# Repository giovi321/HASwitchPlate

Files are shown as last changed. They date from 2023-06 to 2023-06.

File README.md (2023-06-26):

# This is an alternative repository for monunting the display horizontally

The HASwitchPlate project has evolved since. The original creator made a new awesome version, hovewer it is too much work to make the new version compatible with horizontal mounts of the display (i.e., to fit in a 503 electrical box).
Please note that all the pictures in this repository have not been updated to match the horizontal design of the display.
The substantial changes to the design and configuration of the display to make it horizontal are in the folders:
  - 3D_Printable_Models/Horizontal version
  - Nextion_HMI/Horizontal version

The new version of the device and related software and firmware is called [HASPone](https://github.com/HASwitchPlate/HASPone).

---

# HA SwitchPlate

The HA SwitchPlate is a user-programmable LCD touchscreen you can mount into a [standard North American work box](https://www.nema.org/Standards/ComplimentaryDocuments/NEMA%20WD%206%20-%20Dimensions%20for%20Wiring%20Devices%20-%20Excerpt.pdf) in place of a light switch. It connects to your home automation system over WiFi to send and receive [MQTT](https://en.wikipedia.org/wiki/MQTT) messages in response to user interactions on the screen or events happening in your home.  The result is an attractive and highly-customizable controller for your home automation system which you can build yourself!

The HA SwitchPlate ("HASP") utilizes a [Nextion 2.4" LCD Touchscreen display](https://amzn.to/2TRTEU2) mounted in a 3D-printed enclosure as a touchscreen panel for home control and information display.  An [ESP8266-based microcontroller](https://amzn.to/2UZlga4) provides WiFi connectivity and system control.  The project has been developed to integrate with [Home Assistant](https://home-assistant.io/) and [OpenHAB](https://www.openhab.org/) but [should be compatible](Documentation/06_MQTT_Control.md) with any other MQTT-enabled automation platform such as [Domoticz](https://www.domoticz.com/wiki/MQTT), [Node-Red](http://noderedguide.com/tag/mqtt/), [Wink](https://github.com/danielolson13/wink-mqtt), [SmartThings](https://github.com/stjohnjohnson/smartthings-mqtt-bridge), [Vera](https://github.com/jonferreira/vera-mqtt), [HomeKit](https://www.npmjs.com/package/homekit2mqtt), etc.

The [Arduino code](Arduino_Sketch) for the ESP8266 provides a generic gateway between [MQTT](https://en.wikipedia.org/wiki/MQTT) and the [Nextion instruction set](https://www.itead.cc/wiki/Nextion_Instruction_Set).  A basic [Nextion HMI display file](Nextion_HMI) has been included with several pages of various layouts to provide user controls or to present information in response to MQTT messages sent to the device.

## Demo screens

Scene controller Status display Media control Alarm Panel Slider/Dimmer Controls HVAC Controls Light toggles Fan controller WiFi Setup

## Bill of Materials

To build a simple version of this project you will minimally need the [Nextion display](https://amzn.to/2DIpahB) and the [WeMos D1 Mini](https://amzn.to/2Gc92Xs), 4 jumper wires, and a USB cable to power both devices.

A complete build that's ready to install will require the following components:

* [Nextion 2.4" LCD Touchscreen display](https://amzn.to/2RksiXr)
* [WeMos D1 Mini ESP8266 WiFi microcontroller](https://amzn.to/2UZlga4)
* [3D printed switch plate](3D_Printable_Models/)
* [3D printed rear cover](3D_Printable_Models/)
* [Mean Well IRM-03-5 AC to 5VDC Power supply](https://amzn.to/2UUWGa8)
* [PCB](PCB/)
* [2N3904 NPN Transistor](https://amzn.to/2TRuwwD)
* [1k Ohm Resistor](https://amzn.to/2Ec3kTZ)
* [4pin 2.54mm JST-XH PCB header](https://amzn.to/2Eaywmt)
* [Rubber grommet](https://amzn.to/2N6Etny)
* [6" each of white and black 300V 18AWG stranded power cables](https://amzn.to/2EcMmoA)
* [Two M2 self-tapping 6MM screws](https://amzn.to/2V0djBg) (or just any 4-6mm M2 screws) to mount PCB in rear enclosure
* [Four 20mm M2 flathead screws](https://amzn.to/2TQvd9N) and [four 3mm M2 threaded inserts](https://amzn.to/2N511Fh) to fasten both halves of the enclosure together

## Get Started!

[Check out the documentation](Documentation/) to get started building your own HA SwitchPlate.

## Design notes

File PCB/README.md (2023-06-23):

# PCB source files and Gerber outputs

Above you'll find [KiCad](http://kicad-pcb.org/) [schematic](https://github.com/aderusha/HASwitchPlate/blob/master/PCB/HASwitchPlate.sch) and [PCB](https://github.com/aderusha/HASwitchPlate/blob/master/PCB/HASwitchPlate.kicad_pcb) files along with [a ZIP bundle containing complete gerber outputs](https://github.com/aderusha/HASwitchPlate/raw/master/PCB/HASwitchPlate.gerbers.zip) ready to send to [your favorite PCB shop](https://www.allpcb.com/?Mb_InviteId=34099).

I had these manufactured by [AllPCB](https://www.allpcb.com/?Mb_InviteId=60399) and I'm very happy with the results.  The quality has been perfect and their shipping time to the US has been under a week across several orders.  [If you sign up through this link](https://www.allpcb.com/?Mb_InviteId=60399) they credit me some cash that I can use for future projects which helps me out a bit.

HA SwitchPlate PCB

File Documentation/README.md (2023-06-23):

# HA SwitchPlate Documentation

## First, a note of caution

The HA SwitchPlate project requires some basic knowledge of soldering, electronics, Arduino programming, MQTT, and how to safely handle high-voltage AC.  This point bears some repeating so let's try a bigger font to make sure everyone gets it:

# THIS PROJECT INVOLVES MONKEYING WITH HIGH VOLTAGE AND YOU COULD KILL YOURSELF AND/OR SET YOUR HOUSE ON FIRE

The end result is a thing that connects to live voltage and will be placed into your wall for years to come. It will not carry any sort of UL/CE/etc certification.  Proceed with extreme caution.

## With that out of the way, let's get started!

If you want to jump right in, follow the steps below in order to build and setup your device.  Keep reading after that for some background on how this all actually works.

## Step-by-step Instructions

### Step 1 - [Arduino Sketch](01_Arduino_Sketch.md)

Get started with deploying your code to the ESP8266 and getting it connected to WiFi and your MQTT broker.

### Step 2 - [Nextion HMI](02_Nextion_HMI.md)

Next you'll want to flash the Nextion touchscreen with the provided firmware.

### Step 3 - [Electronics Assembly](03_Electronics_Assembly.md)

Now we can hook the ESP8266 to the Nextion HMI and provide power to both.

### Step 4 - [Project Enclosure](04_Project_Enclosure.md)

Time to move from the breadboard into a nice new home suitable for mounting in your wall.

### Step 5 - [Home Assistant](05_Home_Assistant.md)

Utilize the provided Home Assistant automations to control and interact with the panel.

### Step 6 - [MQTT Control](06_MQTT_Control.md)

Time to remove the training wheels and learn to send commands to and from the panel via MQTT.

----

## Frequently Asked Questions

* **Can I install HASP outside of North America?** While the various power supply options for the HASP electronics should offer a solution which can handle line voltage in most countries, the physical installation of the device probably won't work outside of North America.  There is no international standard for the size and shape of workboxes, so things like screw hole locations and overall mounting dimensions used for the HASP are unlikely to work in any workbox outside of North America.
* **Can I use HASP with \<Some Home Automation System\>**?  If your home automation system can send Nextion commands as MQTT payloads, then yes.  Getting it all to work is going to take a lot of work, but it's possible.
* **Can I run HASP without a neutral wire?** Like most smart devices, a HASP installation will require a neutral wire available in the box you're mounting into.

----

## HASwitchPlate Architecture

The complete HA SwitchPlate ("HASP") build consists of 4 physical components:

* Nextion LCD Touchscreen
* ESP8266 WiFi microcontroller
* Power supply and circuit board
* 3D-printed enclosure

In addition, there are three different programming environments involved:

* Nextion Instruction set
* Arduino for ESP8266
* Home Assistant automations (or automation platform of your choice)

## The basics

A home automation system such as Home Assistant can interact with the HASP by sending and receiving MQTT messages to control what appears on the HASP and to respond to user interactions at the HASP.  At its core this project is an Nextion-over-MQTT gateway.  [Nextion Instruction Set](https://nextion.tech/instruction-set/) commands are sent to the HASP via an MQTT message and delivered to the Nextion LCD.  User interactions triggered from the LCD (such as button presses) are sent back out from HASP via MQTT messages to be acted upon by your home automation system.

### Example: one screen button

To illustrate, let's discuss the case of a single button shown on the screen.  Below we see  "page 1", showing a set of 4 buttons arranged vertically and a set of 3 page select buttons at the bottom.

Scene Controls

Referring to the [Nextion Object Reference](02_Nextion_HMI.md#hasp-nextion-object-reference) (more on this later), we find that the top-most button above is an object named `p[1].b[4]`.  When the HASP device shown here powered on, the home automation controller sent an MQTT message that looked like this:

| topic | message |
|---|---|
| `hasp/plate01/command/p[1].b[4].txt` | `"  Lights On "` |

Let's take a look at this `command` message:

`hasp` All messages to and from the HASP appear under the `hasp/` namespace in MQTT

`plate01` This device is named `plate01`.  You can have several HASP devices in your home and each gets their own name.

`command` This message is a `command` being sent *to* the HASP device.

`p[1].b[4]` is the name of a Nextion "object".  A full discussion of these names and a map to the objects included in the HASP project can be found [here](02_Nextion_HMI.md#hasp-nextion-object-reference).

`.txt` is a property of the object named above.  In this case, `.txt` is a reference to the text which appears on this object.

`"     Lights On "` Is the text we wish to appear on the screen.  The `` part of this text is a [FontAwesome icon codepoint](https://fontawesome.com/cheatsheet), which here happens to be a lightbulb.  We've mixed the icon and the text to be displayed in this message.

Put together, we've told the HASP named `plate01` to send a Nextion instruction `p[1].b[4].txt="     Lights On "`.  The HASP sent this command to the Nextion LCD, and the result is the text you see on the screenshot above.

### User Interaction

Now that we have some nice text appearing on the screen, let's see what happens when the user interacts with our button.  When the `Lights On` button is pressed, the Nextion LCD sends a command to the HASP device, which publishes the following MQTT message:

| topic | message |
|---|---|
| `hasp/plate01/state/p[1].b[4]` | `ON` |

Let's take a look at this `state` message:

`hasp` Just as before, all messages to and from the HASP appear under the `hasp/` namespace

`plate01` This message came from a device named `plate01`.

`state` This message is a `state` update sent *from* the HASP device.

`p[1].b[4]` is the Nextion object which triggered the new `state`

`ON` This messages tells us that the object above has entered the `ON` state.  In the case of a button object, this means somebody has pressed the button.  An `OFF` message will be sent later when the user releases the button.

### Responding to User Interaction

Now it is up to your home automation system to pick up this message and doing something meaningful in response, like turning on the lights.  In this project, a set of [Home Assistant automations](https://www.home-assistant.io/docs/automation/) has been provided to demonstrate various interactions which you can use as a starting point for customizing your own environment.

[This is an example Home Assistant automation which will listen for HASP button presses](../Home_Assistant/packages/plate01/hasp_plate01_p1_scenes.yaml#L45-L53):

```yaml
# Trigger scene.lights_on when p[1].b[4] pressed
- alias: hasp_plate01_p1_SceneButton4
  trigger:
    - platform: mqtt
      topic: "hasp/plate01/state/p[1].b[4]"
      payload: "ON"
  action:
    - service: scene.turn_on
      entity_id: scene.lights_on
```

This automation tells Home Assistant to listen to the MQTT topic `hasp/plate01/state/p[1].b[4]` for a message with the payload `ON`.  As we learned above, this is the message that will be sent out when a user presses the button which we've applied the text label "Lights on" (with a nice icon).  When Home Assistant receives this button press, we trigger a [Home Assistant scene](https://www.home-assistant.io/docs/scene/) called `lights_on`.

And that's it!  All of the HASP interactions follow some version of this basic workflow.  The device is configured to display things by receiving MQTT messages.  When the user does things at the HASP device, MQTT messages are sent back for your home automation platform to respond to.

Of course, things can get complicated.  The included automations make extensive use of [templates](https://www.home-assistant.io/docs/automation/templating/) and other advanced features of Home Assistant.  Don't be worried though, underneath it all it's always going to be some version of the simple interaction shown above.

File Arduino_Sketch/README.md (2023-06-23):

# HASwitchPlate Arduino Sketch

Here you'll find the [Arduino source code](./HASwitchPlate/HASwitchPlate.ino) for the microcontroller firmware along with [a pre-compiled binary image](https://github.com/aderusha/HASwitchPlate/raw/master/Arduino_Sketch/HASwitchPlate.ino.d1_mini.bin) which can be [flashed directly to your ESP8266](../Documentation/01_Arduino_Sketch.md#nodemcu-flasher).  

Please [check the Arduino Sketch documentation](../Documentation/01_Arduino_Sketch.md) for additional deployment details.

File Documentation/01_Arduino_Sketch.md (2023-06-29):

# Flash firmware to ESP8266

The first order of business will be to flash the provided firmware to the ESP8266.  You can do this using the [NodeMCU Flasher](#nodemcu-flasher) (easy, Windows-only) or the [Arduino IDE](#arduino-ide) (less easy, but cross-platform).  You should only need to run through this process once as future firmware updates can be applied through the provided web interface.

## NodeMCU Flasher

If you're running Windows and you just want to get started without dealing with Arduino this is probably going to be your best option.

### Required Downloads

* NodeMCU Flasher: [Win32](https://github.com/nodemcu/nodemcu-flasher/raw/master/Win32/Release/ESP8266Flasher.exe) / [Win64](https://github.com/nodemcu/nodemcu-flasher/raw/master/Win64/Release/ESP8266Flasher.exe)
* [HASwitchPlate Firmware](https://github.com/giovi321/HASwitchPlate/raw/master/Arduino_Sketch/HASwitchPlate.ino.d1_mini.bin)

### NodeMCU Flasher Process

* Plug your WeMos D1 into an available USB port on your PC
* Launch the NodeMCU flasher and select the COM port for your device from the `COM Port` drop-down menu
* Select the `Config` tab<sup>(1)</sup>, then click the top-most gear icon to the right<sup>(2)</sup> to open a file browser. NodeMCU_Flasher_OpenFirmware
* Navigate to the HASP firmware image you downloaded and click `Open` to select it
* Switch back to the `Operation` tab and click `Flash(F)`

Now proceed to [First-time Setup](#first-time-setup) to connect to your wireless network.

---

## Arduino IDE

[Download the IDE for your platform](https://www.arduino.cc/en/Main/Software) and [follow these instructions to add support for the ESP8266 platform](https://github.com/esp8266/Arduino#installing-with-boards-manager).  HASP is currently compiled with Arduino core for ESP8266 version 2.5.0.  Once this is installed, select the board `LOLIN(WEMOS) D1 R2 & mini` from 'Tools' > 'Board'

### Required Libraries

Next you will need to add several libraries to your Arduino environment.  [Follow this guide for the general process](https://www.arduino.cc/en/Guide/Libraries) and add the following libraries to your IDE:

* [ArduinoJson](https://github.com/bblanchon/ArduinoJson) by Benoit Blanchon version 6.15
* [MQTT](https://github.com/256dpi/arduino-mqtt) by Joel Gaehwiler version 2.4.7
* [WiFiManager](https://github.com/tzapu/WiFiManager) by tzapu version 0.15.0

To enable future firmware updates you'll need to modify settings in the Arudino IDE for 1M SPIFFs, leaving 3M free for code and updates.  In the Arduino IDE select `Tools` > `Flash Size:` > `4M (1M SPIFFS)`.  If you're using [PlatformIO](https://platformio.org/) instead of Arduino, [modify the build flags](http://docs.platformio.org/en/latest/platforms/espressif8266.html#flash-size) to include `-Wl,-Teagle.flash.4m1m.ld`
Arduino Erase All Flash Contents

## First-time Setup

Once your device has been flashed, restart it and connect to the WiFi SSID and password displayed on the LCD panel (or serial output if you don't have the LCD ready).  You should be prompted to open a [configuration website](http://192.168.4.1) to find your WiFi network and password.  You can set the MQTT broker information and admin credentials now, or use the web interface to do so later.  Once you `save settings` the device will connect to your network.  Congratulations, you are now online!

WiFi Config 0 WiFi Config 1 WiFi Config 2

## Firmware updates

After the initial firmware deployment you should be able to upload new firmware through the web admin interface or [using Arduino OTA updates](https://randomnerdtutorials.com/esp8266-ota-updates-with-arduino-ide-over-the-air/) without connecting to your device via USB.

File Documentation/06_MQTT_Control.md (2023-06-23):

# MQTT Control

## MQTT

[MQTT](https://mqtt.org/faq) is a standard IoT protocol in widespread use everywhere from small home automation projects to global industrial IoT environments.  Think of it as a "twitter for devices" - it works in very much the same way.  MQTT is a "publish/subscribe" message bus, where attached devices can publish `messages` on `topics`, and other devices can subscribe to those `topics` to receive the published message.  MQTT requires a central MQTT server we call a "broker".  Built-in MQTT broker services are available in [Home Assistant](https://www.home-assistant.io/docs/mqtt/broker/) and [OpenHAB](https://www.openhab.org/addons/bindings/mqtt/) or you can run your own standalone instance.  The [Mosquitto](https://mosquitto.org/) MQTT broker is a common open source solution and is probably a good place to start for home use.

At its core, the HASP project acts as a gateway between MQTT and the Nextion LCD.  It will "subscribe" to MQTT messages sent by your home automation software and forward the contents of those messages to the Nextion LCD.  Interactions from the LCD, such as a user pressing a button, are sent back to your home automation system as published MQTT messages.

In order to make use of the HASP project to its full potential, you'll need to understand how the Nextion LCD sends and receives commands, and how to make your home automation system interact with those commands over MQTT.

## Nextion Instructions

A detailed guide to the Nextion instruction set can be found [here](https://nextion.itead.cc/resources/documents/instruction-set/).  A mostly-complete list of all available instructions and their use is available [here](https://www.itead.cc/wiki/Nextion_Instruction_Set).  These Nextion instructions are sent as MQTT messages per the [`MQTT Namespace`](#mqtt-namespace) outlined below.

A common issue people encounter centers around the use of quotes in the Nextion instruction set.  As a general rule, attributes which accept only numbers do not have quotes, and all other values must be enclosed in double quotes.

## Nextion Page and Object IDs

Objects are referenced by page number (*not page name*) and object ID (*not object name*) as shown in the Nextion editor.  The Nextion notation for each object is of the form `p[1].b[2]` meaning page number 1, object ID 2.  Confusingly, button object *names* will start at `b0` but it might be object ID 2, or 7, etc. Other objects will be named similarly with different letters.  For example, the first text field on the page will be automatically named `t0`.  **Ignore these names**.  They have nothing to do with the object ID, and all objects regardless of type are still referenced as `p[<page number>].b[<object id>]`

Page and Object IDs

Screenshots of each object number on each page of the HASP project can be found in the [Nextion HMI documentation section](02_Nextion_HMI.md#hasp-nextion-object-reference).

An object will have multiple attributes, some of which can be changed.  For example, a button named `p[1].b[2]` may have a "txt" attribute which we'd refer to as `p[1].b[2].txt`.  Not all attributes can be changed at runtime, the ones which can are shown in a green font in the Nextion editor (see the right pane of the image above.)

## MQTT Message Examples

With the information above we can now take a look at a some example MQTT  transactions.  To begin, let's customize the text appearing on a button.  The [topmost button on page one](02_Nextion_HMI.md#pages-1-3) is `p[1].b[4]`.  If we want to set the text on that button to read `HASP` we could send the following MQTT message:

> topic: `hasp/plate01/command/p[1].b[4].txt`  
> message: `"HASP"`

The HASP device named `plate01` will be subscribed to the topic `hasp/plate01/command`.  When it sees this message, it will send the Nextion LCD the command `p[1].b[4].txt="HASP"` which will update the text on our button.

Now let's try one going the other way.  When a user presses that button, HASP is going to publish an MQTT message that looks like this:

> topic: `hasp/plate01/state/p[1].b[4]`  
> message: `ON`  

Your home automation system will be subscribed to `hasp/plate01/state`.  When the message example above is published, your home automation system will know that somebody pressed button `p[1].b[4]` on a HASP device named `plate01` and can take appropriate action in response.

## Home Assistant Automation Example

The HASP project includes [a number of Home Assistant automations](../Home_Assistant) to get you up and running.  To make full use of your HASP you will want to customize these automations to suit your own needs.  The example automations provided are broken down into pages, and the ideas presented build on each other as you work through each page in numerical order.  If you're looking to understand how this works, [start with page 1](../Home_Assistant/packages/plate01/hasp_plate01_p1_scenes.yaml) and work your way up through the rest.

Let's take a look at an automation example to handle the `p[1].b[4]` button we were just working with.  The automations discussed here will be specific to Home Assistant but the concepts should apply to any home automation platform.

### Send commands from Home Assistant to the HASP

[The first page 1 automation](../Home_Assistant/packages/plate01/hasp_plate01_p1_scenes.yaml#L6-L21), like most Home Assistant automations, begins with a [trigger](https://www.home-assistant.io/docs/automation/trigger/).  Ours looks like this:

```yaml
  - alias: hasp_plate01_p1_ScenesInit
    trigger:
    - platform: state
      entity_id: 'binary_sensor.plate01_connected'
      to: 'on'
    - platform: homeassistant
      event: start
```

This trigger will fire whenever the HASP device `plate01` connects to Home Assistant, or whenever Home Assistant starts.  When the HASP starts up it has no text on any buttons, so the first thing we'll do is start sending commands to tell the HASP what we want our buttons to say.  Let's look at the [action](https://www.home-assistant.io/docs/automation/action/) section:

```yaml
    action:
    - service: mqtt.publish
      data:
        topic: 'hasp/plate01/command/p[1].b[4].font'
        payload: '2'
    - service: mqtt.publish
      data:
        topic: 'hasp/plate01/command/p[1].b[4].txt'
        payload: '"Lights On"'
```

The first action tells Home Assistant to publish the message `2` on the topic `hasp/plate01/command/p[1].b[4].font`.  This command sets the font for our button to [font number 2](02_Nextion_HMI.md#hasp-default-fonts) which "Consolas 48 point".  That font allows us to fit 10 characters into a standard-sized button.

Our next action tells Home Assistant to publish the message `"Lights On"` on the topic `hasp/plate01/command/p[1].b[4].txt`.  Note the use of quotes here, as we're sending text instead of a numeric value.  This command will program button `p[1].b[4]` to show the text `Lights On`.

If you would like this button to say something else, you can make that change now and restart Home Assistant to see what happens.

### Send commands from HASP to Home Assistant

[The second page 1 automation](../Home_Assistant/packages/plate01/hasp_plate01_p1_scenes.yaml#L47-L55) in our example looks like this:

```yaml
# Trigger scene.lights_on when p[1].b[4] pressed
  - alias: hasp_plate01_p1_SceneButton4
    trigger:
    - platform: mqtt
      topic: 'hasp/plate01/state/p[1].b[4]'
      payload: 'ON'
    action:
    - service: scene.turn_on
      entity_id: scene.lights_on
```

This automation is `trigger`ed when Home Assistant receives the message `ON` in the topic `hasp/plate01/state/p[1].b[4]`.  The `action:` calls a [Home Assistant scene](https://www.home-assistant.io/components/scene/) called `lights_on` which was [defined elsewhere](../Home_Assistant/packages/hasp_demo.yaml#L43-L57).

You can [change the action](https://www.home-assistant.io/docs/automation/action/) to be anything that Home Assistant can do - [turn on a light](https://www.home-assistant.io/components/light/#service-lightturn_on), [play a song](https://www.home-assistant.io/components/media_player/#service-media_playerplay_media), [notify a user over SMS](https://www.home-assistant.io/components/notify.twilio_sms/#usage), or whatever else you can think of.

## MQTT Namespace

By default the device will subscribe to `hasp/<node_name>/command/#` to accept incoming commands.  The device will also subscribe to `hasp/<group_name>/command/#` to accept incoming commands aimed at a group of devices.

There are two subtopics to send commands to and receive messages from the panel:

* `command` will send commands or set attribute of the display, such as button text or screen dim. The specific attribute must be appended as a subtopic, with the value to be set delivered as the payload.  For example, the following command will set the text displayed on page 1/button 4 to "Lamp On": `mosquitto_pub -h mqtt -t hasp/plate01/command/p[1].b[4].txt -m '"Lamp On"'`
* `state` topics will be sent by the panel in response to local user interactions or received commands which provide output in return.  For example, a user pressing button 4 on page 1 will cause the panel to publish a message: `'hasp/plate01/state/p[1].b[4]' 'ON'`

## `command` Syntax

Messages sent to the panel under the `command` topic will be handled based on the following rules:

* **`-t 'hasp/plate01/command' -m 'dim=50'`** A `command` with no subtopic will send the command in the payload to the panel directly.
* **`-t 'hasp/plate01/command/page' -m '1'`** The `page` command subtopic will set the current page on the device to the page number included in the payload.
* **`-t 'hasp/plate01/command/json' -m '["dim=50", "page 1"]'`** The `json` command subtopic will send a JSON array of commands one-by-one to the panel.
* **`-t 'hasp/plate01/command/p[1].b[4].txt' -m '"Lamp On"'`** A `command` with a subtopic will set the attribute named in the subtopic to the value sent in the payload.
* **`-t 'hasp/plate01/command/p[1].b[4].txt' -m ''`** A `command` with a subtopic and an empty payload will request the current value of the attribute named in the subtopic from the panel.  The value will be returned under the `state` topic as `'hasp/plate01/state/p[1].b[4].txt' -m '"Lamp On"'`
* **`-t 'hasp/plate01/command/statusupdate'`** `statusupdate` will publish a JSON string indicating system status.
* **`-t 'hasp/plate01/command/reboot'`** The `reboot` command will reboot the HASP device.
* **`-t 'hasp/plate01/command/factoryreset'`** The `factoryreset` command will wipe out saved WiFi, nodename, and MQTT broker details to reset the device back to default settings.
* **`-t 'hasp/plate01/command/lcdupdate'`** The `lcdupdate` command subtopic with no message will attempt to update the Nextion from the HASP GitHub repository.
* **`-t 'hasp/plate01/command/lcdupdate' -m 'http://192.168.0.10:8123/local/HASwitchPlate.tft'`** The `lcdupdate` command subtopic attempts to update the Nextion from the HTTP URL named in the payload.
* **`-t 'hasp/plate01/command/espupdate'`** The `espupdate` command subtopic with no message will attempt to update the ESP8266 from the HASP GitHub repository.
* **`-t 'hasp/plate01/command/espupdate' -m 'http://192.168.0.10/local/HASwitchPlate.ino.d1_mini.bin'`** The `espdupdate` command subtopic attempts to update the ESP8266 from the HTTP URL named in the payload.

In each of those commands, you can substitute the `<node_name>` for the `<group_name>` if you want to target all devices in a group.

### MQTT Error codes (rc=n)

If the HASP cannot connect to MQTT it will display a return code on the screen as RC=_n_.  These codes are specified by the MQTT spec [here](http://docs.oasis-open.org/mqtt/mqtt/v3.1.1/os/mqtt-v3.1.1-os.html#_Table_3.1_-).

| Value | Return Code Response | Description |
|---|---|---|
| 0 | 0x00 Connection Accepted | Connection accepted |
| 1 | 0x01 Connection Refused, unacceptable protocol version | The Server does not support the level of the MQTT protocol requested by the Client |
| 2 | 0x02 Connection Refused, identifier rejected | The Client identifier is correct UTF-8 but not allowed by the Server |
| 3 | 0x03 Connection Refused, Server unavailable | The Network Connection has been made but the MQTT service is unavailable |
| 4 | 0x04 Connection Refused, bad user name or password | The data in the user name or password is malformed |
| 5 | 0x05 Connection Refused, not authorized | The Client is not authorized to connect |
| 6-255 | | Reserved for future use |

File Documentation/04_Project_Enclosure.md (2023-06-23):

# Project Enclosure

## 3D Printed Enclosure

The [enclosure provided](../3D_Printable_Models) includes STL files ready for slicing and the source models editable in the free edition of [SketchUp Make](https://www.sketchup.com/download).

## Assembling the completed project

### High voltage AC cabling

The AC power cables should be at least 18AWG 300V stranded cable with a white jacket soldered to the `AC/N` pad on the PCB and a similar wire with a black jacket soldered to `AC/L`.  These are fed through a [rubber push-in grommet](https://amzn.to/2N6Etny) mounted into the rear enclosure.  I've had good luck stripping an existing 3 conductor power cord and using the black/white wires inside.

### Threaded Inserts

The two halves of the enclosure are held together by [four 20mm M2 flat-head screws](https://amzn.to/2TQvd9N) through the rear of the enclosure into a set of [four 3mm M2 threaded inserts](https://amzn.to/2N511Fh) installed into the front plate.

To install the threaded inserts in the front plate, thread the end of an M2 screw into the insert with the end of the screw flush with the bottom face of the insert (meaning, it's not sticking out the other side).  Apply a thin bead of slow-set superglue around the outside edge of the insert, taking care not to get glue on the screw itself as you don't want to pull the glue up into the threads when removing the screw.  Then, take a hammer and *gently* tap it into place on the front plate.  You can crack the plastic if you swing too hard, you just need enough force to push the knurled ridges on the outside of the insert into the plate.

### PCB Installation

Installing the [HASP PCB](../PCB) requires a pair of small m2-ish screws, I'm using [M2 self-tapping 6MM screws](https://amzn.to/2V0djBg) but most any 4-6mm M2 screws should work fine too.  There shouldn't be much strain on these two so I haven't bothered with inserts here.

Parts installed

Once everything is fit together then it's a simple matter of running the four 20mm m2 screws through the back to hold the two halves of the enclosure together.  Again, be careful not to tighten these too hard as the screws can dimple the front of the switch plate.  Now you should be ready to mount into the wall!

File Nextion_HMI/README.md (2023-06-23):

# Redesigned horizontal version for usage in other countries with 503 electrical box

See the folder "New version" for the correct files. All the rest stays the same.

---

# Nextion HMI

The Nextion panel ships with a default demo configuration which we need to overwrite with the included compiled code.  The file [HASwitchPlate.tft](HASwitchPlate.tft) can be saved to a FAT32-formatted microSD card and placed into the panel before power on.  The panel will recognize the code update and load it automatically, after which you're ready to connect to the microcontroller.  Note that some users have reported problems with cards formatted under Linux, so use a Windows system for this process and it should work without trouble.

If you want to manually edit your own panels, [download the editor from Nextion](https://nextion.itead.cc/resource/download/nextion-editor/) and you can flash the panel directly via serial.

Please [check the Nextion HMI documentation](../Documentation/02_Nextion_HMI.md) for additional details.

## Nextion Files Explained

* **[HASwitchPlate.hmi](HASwitchPlate.hmi)** This is the "source" file which you can modify in the [Nextion editor](https://nextion.itead.cc/resource/download/nextion-editor/).  If you want to make your own Nextion HMI, I'd recommend starting with this file, keeping Page 0 (`p0`), then start your own design on pages 1+.
* **[HASwitchPlate.tft](HASwitchPlate.tft)** This is the compiled Nextion firmware for the HASwitchPlate usable on a standard Nextion 2.4" LCD, model `NX3224T024_011R`
* **[HASwitchPlate-Enhanced.tft](HASwitchPlate-Enhanced.tft)** This is the compiled Nextion firmware for the HASwitchPlate usable on an enhanced Nextion 2.4" LCD, model `NX4024K032_011R`.  This panel will not fit in the provided 3D printed enclosure and no enhanced features are used in this project.  **Don't buy this panel**, but if you did (*and you shouldn't*), you can use this firmware.
* **[HASwitchPlate-TJC.hmi](HASwitchPlate-TJC.hmi)** This is the "source" file for the Chinese-market TJC LCD model `TJC3224T024_011`.  This file cannot be used with the english language editor.  If you purchase this panel, you will need to use the Chinese-language "USART HMI" editor to modify this file.  **Don't buy this panel**.
* **[HASwitchPlate-TJC.tft](HASwitchPlate-TJC.tft)** This is the compiled Nextion firmware for the HASwitchPlate usable on a Chinese market TJC 2.4" LCD, model `TJC3224T024_011`.

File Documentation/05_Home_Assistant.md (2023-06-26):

# Home Assistant integration

Configuring Home Assistant for the HASP requires making some basic changes to your configuration and downloading the packages to your installation.  [Continue below]((#standard-home-assistant-installation) for a standard Home Assistant installation in a container (HassOS, HassIO, Docker, etc).

The procedure will be a little different if you're running Home Assistant Core (venv, hassbian, or similar), so [skip to that section](#home-assistant-core-installation).

Finally, if you'd rather make all the changes yourself, jump to the [Manual Home Assistant installation section](#manual-home-assistant-installation).

## Standard Home Assistant installation

Before deploying your first HASP device, you'll need to install and configure the [`Mosquitto broker`](https://www.home-assistant.io/addons/mosquitto/) and [`Terminal & SSH`](https://www.home-assistant.io/addons/ssh/) add-ons from the default repository.  Be sure to follow the configuration instructions provided for both add-ons.

The mosquitto broker package requires a username and password.  Be sure to configure the "MQTT User" and "MQTT Password" on the HASP with a valid user from your Home Assistant configuration, and set the broker to the IP address of your Hass.io installation.  You will also need to setup the MQTT Integration (`Configuration` > `Integrations` > `MQTT` > `CONFIGURE`) and check the box `Enable discovery`.

Once those are installed, configured, and started, you can open the Terminal and execute the following command:

```bash
bash <(wget -qO- -o /dev/null https://raw.githubusercontent.com/giovi321/HASwitchPlate/master/Home_Assistant/deployhasp.sh)
```

You will be prompted for a device name and the script will do the rest.  Once it completes, the script will display a Lovelace configuration which you can paste into your existing Home Assistant UI through the Lovelace editor.

To apply your changes, restart Home Assistant (`Configuration` > `Server Controls` > `Server management` > `RESTART`) and then continue to the [First time setup](#first-time-setup) section below to initialize your environment.

[Check out this video](https://youtu.be/wbtVfuDKaM4) for the complete process of starting up a new Hass.io installation, configuring the required add-ons, and setting up your first HASP device.

---

## Home Assistant Core installation

Before deploying your first HASP device, you'll need to install and configure an [MQTT broker](https://www.home-assistant.io/docs/mqtt/broker) for Home Assistant.

You'll need to ssh to your Home Assistant installation as a user who has access to write to your home assistant installation.  For most installations, this will be the user `homeassistant`.

```bash
sudo su -s /bin/bash homeassistant
cd ~/.homeassistant
bash <(wget -qO- -o /dev/null https://raw.githubusercontent.com/giovi321/HASwitchPlate/master/Home_Assistant/deployhasp.sh)
```

You will be prompted for a device name and the script will do the rest.  Once it completes, restart your Home Assistant service to apply changes and then continue to the [First time setup](#first-time-setup) section below to initialize your environment.

---

## Manual Home Assistant installation

### `configuration.yaml` changes

To deploy your first HASP device into Home Assistant a couple simple changes will need to be made to your `configuration.yaml`.  [See the documentation here](https://www.home-assistant.io/getting-started/configuration/) for the general process of editing that file.  These changes only need to be made once, if you are adding additional HASP devices to an existing installation you can skip directly to the [`deployhasp.sh`](#deployhaspsh) section below.

### Packages

The configuration and automation files for the HASP are bundled as [Home Assistant Packages](https://www.home-assistant.io/docs/configuration/packages/).  Enable packages under the `homeassistant` section at the top of your `configuration.yaml` by adding the following line:

```yaml
homeassistant:
  packages: !include_dir_named packages
```

### MQTT

This project relies on communication with an [MQTT broker](https://www.home-assistant.io/docs/mqtt/broker).  You will need to enable Home Assistant MQTT support by following that guide.

### Recorder

The [Home Assistant Recorder](https://www.home-assistant.io/components/recorder/) component is required to allow Home Assistant to save configuration and state of some HASP controls across reboots.  You will can enable Home Assistant Recorder by adding the following line to your `configuration.yaml`:

```yaml
# Example configuration.yaml entry
recorder:
```

### `deployhasp.sh`

Now you'll need to copy over the [packages directory](https://github.com/giovi321/HASwitchPlate/tree/master/Home_Assistant/packages) and modify it for your new device.  The folder name, file names, and the contents of the `.yaml` files will all need to have `plate01` replaced with your new device name.

The `deployhasp.sh` script will automate this task and can be executed with the following commands:

```bash
sudo su -s /bin/bash homeassistant
cd ~/.homeassistant
bash <(wget -qO- -o /dev/null https://raw.githubusercontent.com/giovi321/HASwitchPlate/master/Home_Assistant/deployhasp.sh)
```

Finally, you'll need to restart Home Assistant to apply your changes then continue to the [First time setup](#first-time-setup) section below to initialize your environment.

---

## First time setup

## Lovelace configuration

Lovelace doesn't support automation of the UI so a few manual steps need to happen next

Upon startup the default HMI display file contains empty buttons with no text.  Launch the Home Assistant web UI and look for a new tab with your chosen device name.  Select that tab and look for the automation titled `hasp_<your_device_name>_00_FirstTimeSetup`.  Select that automation and click "TRIGGER" to apply the basic configuration to your new device.

Home_Assistant_FirstTimeSetup

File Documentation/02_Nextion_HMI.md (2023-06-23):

# Nextion HMI

## Basic first-time use

For most users the deployment of the Nextion firmware is straightforward - simply copy [the compiled firmware image](../Nextion_HMI/HASwitchPlate.tft) to a [FAT32-formatted microSD card](https://nextion.tech/faq-items/using-nextion-microsd/), insert the microSD card into the Nextion LCD, and then apply 5VDC to the power pins on the panel.  It should power up the panel, recognize the .TFT file, and update the panel automatically.  Once the firmware update has completed you can remove power and eject the microSD card.

Compiled TFT files are included for the [Basic](https://github.com/aderusha/HASwitchPlate/raw/master/Nextion_HMI/HASwitchPlate.tft) and [Enhanced](https://github.com/aderusha/HASwitchPlate/raw/master/Nextion_HMI/HASwitchPlate-Enhanced.tft) versions of the panel.  This project does not currently utilize any features offered in the Enhanced panel, and the Enhanced device does not fit in the provided enclosure.  **It is strongly recommended that you do not use the enhanced display**.

Once the project is assembled, future updates to the Nextion firmware can be handled over-the-air by utilizing the built-in web interface or by [issuing an MQTT command](06_MQTT_Control.md#command-syntax) with a URL to the target TFT file.

With the Nextion firmware flashed you can proceed to the [Electronics Assembly section](03_Electronics_Assembly.md) to test the assembled system.

---

## Nextion Editor

For advanced customization you will need to download the (Windows-only) [Nextion editor](https://nextion.tech/nextion-editor/).  You can find instructions on its use [here](https://www.itead.cc/blog/nextion-editor-a-basic-introduction).

If you want to edit the existing HASP interface, you will likely need to delete some pages in order to add your own work as the project consumes nearly the entire memory space of the Nextion basic panel.  If you'd like to start a new interface from the ground up, copy over the existing Page 0 page as the ESP8266 firmware makes use of page 0 for user interactions and WiFi setup.  The Home Assistant automations will probably need to be changed if any major modifications are made to the HMI.

## Nextion Page and Object IDs

Objects are referenced by page number (*not page name*) and object ID (*not object name*) as shown in the Nextion editor.  The Nextion notation for each object is of the form `p[1].b[2]` meaning page number 1, object ID 2.  Confusingly, button object *names* will start at `b0` but it might be object ID 2, or 7, etc. Other objects will be named similarly with different letters.  For example, the first text field on the page will be automatically named `t0`.  **Ignore these names**.  They have nothing to do with the object ID, and all objects regardless of type are still referenced as `p[<page number>].b[<object id>]`

Page and Object IDs

Screenshots of each object number on each page of the HASP project can be found in the [Nextion HMI documentation section](02_Nextion_HMI.md#hasp-nextion-object-reference).

An object will have multiple attributes, some of which can be changed.  For example, a button named `p[1].b[2]` may have a "txt" attribute which we'd refer to as `p[1].b[2].txt`.  Not all attributes can be changed at runtime, the ones which can are shown in a green font in the Nextion editor (see the right pane of the image above.)

## Nextion Instruction Set

The Nextion accepts and sends commands over the serial interface.  Your Home Automation system will send Nextion instructions wrapped in an MQTT message to be delivered by HASP to your display.  A detailed guide to the Nextion instruction set can be found [here](https://nextion.tech/instruction-set/).

## Nextion color codes

The Nextion environment utilizes RGB 565 encoding.  [Use this handy convertor](https://nodtem66.github.io/nextion-hmi-color-convert/index.html) to select your colors and convert to the RGB 565 format.

## HASP Nextion Object Reference

| Page 0 | Pages 1-3 | Pages 4-5 |
|---|---|---|
| Page 0 | Pages 1-3 | Pages 4-5 |

| Page 6 | Page 7 | Page 8 |
|---|---|---|
| Page 6 | Page 7 | Page 8 |

| Page 9 | Page 10 | Page 11 |
|---|---|---|
| Page 9 | Page 10 | Page 11

## HASP Default Fonts

The Nextion display supports monospaced and proportional fonts.  For proportional fonts, the HASP project includes [Consolas](https://docs.microsoft.com/en-us/typography/font-list/consolas) in 4 sizes and [Webdings](https://en.wikipedia.org/wiki/Webdings#Character_set) in 1 size.

| Number | Font | Max characters per line | Max lines per button |
|---|---|---|---|
| 0 | Consolas 24 point | 20 characters | 2 lines |
| 1 | Consolas 32 point | 15 characters | 2 lines |
| 2 | Consolas 48 point | 10 characters | 1 lines |
| 3 | Consolas 80 point | 6 characters | 1 lines |
| 4 | Webdings 56 point | 8 characters | 1 lines |

The HASP also includes [Google's "Noto Sans"](https://github.com/googlefonts/noto-fonts) proportional font in 5 sizes.  These fonts also have the "[FontAwesome](https://fontawesome.com/cheatsheet)" icon set which can be mixed with normal ASCII text.

| Number | Font |
|---|---|
| 5 | Noto Sans Regular 24 point |
| 6 | Noto Sans Regular 32 point |
| 7 | Noto Sans Regular 48 point |
| 8 | Noto Sans Regular 64 point |
| 9 | Noto Sans Regular 80 point |
| 10 | Noto Sans Bold 80 point |

HASP Fonts 0-3 HASP Fonts 4-7 HASP Fonts 8-10

## Using FontAwesome Icons

FontAwesome ("FA") icons are now included with HASP in fonts 6-10 (`Noto Sans` fonts).  To use these, open the [FontAwesome Cheat Sheet](https://fontawesome.com/cheatsheet), browse to any of the "Solid", "Regular", or "Brands" pages, highlight the icon in your browser, and then paste the result into your automation or the Nextion editor.  The result in your editor should look like this: 

When sent to your LCD with the appropriate font selected (again, only fonts 6-10), the icon should show up as seen on the Cheat Sheet.  You can also mix text and icons in the same string.

Using FontAwesome Icons

## HOW TO: Run this software with an ESP8266 only

One feature of the Nextion Editor is the [Nextion Simulator](https://www.itead.cc/wiki/Nextion_Editor_Quick_Start_Guide#Debug.2C_online_simulator), which allows the user to debug an HMI being edited.  You've probably used this if you've worked on editing your own HMI file.  You can run through the screens using your mouse to issue touch commands and feed it commands and see output in the text boxes provided.

The Nextion simulator allows you to run [hardware-in-loop](https://en.wikipedia.org/wiki/Hardware-in-the-loop_simulation) with your microcontroller.  If you have a second USB UART kicking around (you could use a second WeMos or Arduino if you have one handy), connect the UART RX to pin D4 and the TX to pin D7 which are the pins you'd use to hook up a real panel.  In the Nextion Simulator you can then select "User MCU Input", select your UARTs COM port, set the Baud to 115200, then click Start.

Now the Simulator will accept input from and send output to your flashed ESP8266 without having a Nextion on hand!

Nextion Editor Simulator

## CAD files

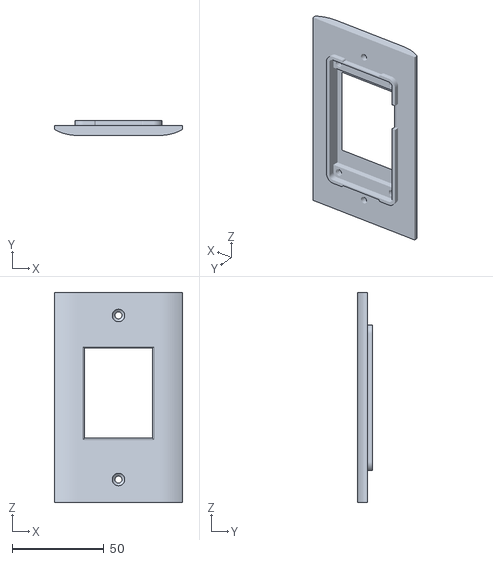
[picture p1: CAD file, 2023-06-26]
3D_Printable_Models/HASwitchPlate_new_front_v1.stl
69.8 x 8.00 x 114.3

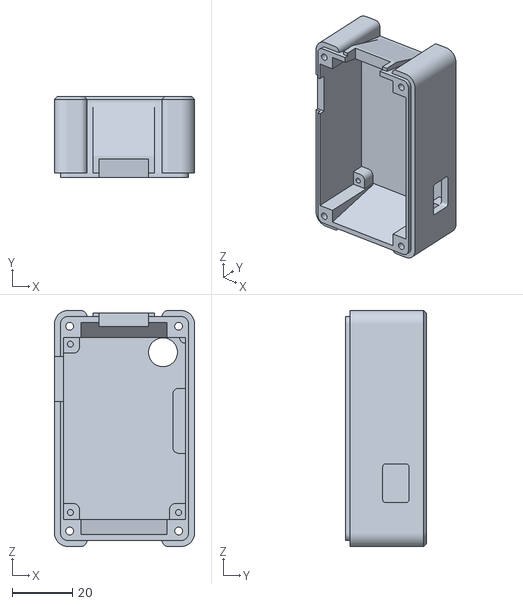
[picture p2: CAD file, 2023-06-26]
3D_Printable_Models/HASwitchPlate_new_back_v1.stl
46.6 x 27.1 x 78.5

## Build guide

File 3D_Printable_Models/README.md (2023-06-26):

# Redesigned horizontal version for usage in other countries with 503 electrical box
See the folder "Horizontal version" for the correct files. All the rest stays the same.

Printing: I have printed those with a resin printer, everything fits perfecly. However, I suggest to glue the cover to the face plate instead of using screws as it was originally designed for use with a filament printer and the screws might not fit using a resin printer.

The design adapts to the following box:



And looks like this:


# Switch Plate model for other countries' single-gang workbox

## 3D Printed Enclosure

Above you'll find STL files ready for slicing and the source models editable in the free edition of [SketchUp Make](https://www.sketchup.com/download).  There are several models presented here for various plate configurations on the front and two options for the rear enclosure.

For most users, you'll want to print [HASwitchPlate_front_single.stl](HASwitchPlate_front_single.stl) and [HASwitchPlate_rear_nolcdmod.stl](HASwitchPlate_rear_nolcdmod.stl).

### Front plate models

* **[HASwitchPlate_front_single.stl](HASwitchPlate_front_single.stl)** Standard single-wide plate. `[HASP]`
* **[HASwitchPlate_front_2x_hasp_decora.stl](HASwitchPlate_front_2x_hasp_decora.stl)** Double-wide plate with Decora switch to the right `[HASP|Decora]`
* **[HASwitchPlate_front_2x_hasp_toggle.stl](HASwitchPlate_front_2x_hasp_toggle.stl)** Double-wide plate with toggle switch to the right `[HASP|toggle]`
* **[HASwitchPlate_front_3x_hasp_decora_decora.stl](HASwitchPlate_front_3x_hasp_decora_decora.stl)** Triple-wide plate with Decora switches to the right `[HASP|Decora|Decora]`
* **[HASwitchPlate_front_3x_hasp_toggle_toggle.stl](HASwitchPlate_front_3x_hasp_toggle_toggle.stl)** Triple-wide plate with toggle switches to the right `[HASP|toggle|toggle]`
* **[HASwitchPlate_front_5x_decora_decora_hasp_decora_decora.stl](HASwitchPlate_front_5x_decora_decora_hasp_decora_decora.stl)** 5-wide plate with 4x Decora switches and HASP in center `[Decora|Decora|HASP|Decora|Decora]`
* **[HASwitchPlate_front_single_dev.stl](HASwitchPlate_front_single_dev.stl)** Standard single-wide plate with SD card exposed for development use (unsafe!) `[HASP]`

### Rear enclosure models

* **[HASwitchPlate_rear_lcdmod.stl](HASwitchPlate_rear_lcdmod.stl)** The `lcdmod` enclosure requires the removal of the 4-pin XHP connector from the Nextion LCD panel.  This option allows for better clearance around the screw posts which may help in tight work boxes, but the process of safely removing the connecter may require a hot air station.
* **[HASwitchPlate_rear_nolcdmod.stl](HASwitchPlate_rear_nolcdmod.stl)** The `nolcdmod` enclosure does not require removing the 4-pin XHP connector from the Nextion LCD panel.  This simplifies the build process but has just a little less room behind the device for the work box screws.  We're not talking a lot here, so if you don't have the hot air station this option will probably work fine for you.
* **[HASwitchPlate_rear_lcdmod_minimum_clearance.stl](HASwitchPlate_rear_lcdmod_minimum_clearance.stl)** The `lcdmod_minimum_clearance` rear enclosure has been modified to provide the tightest fit around the HASP components that I can work out.  The walls are flimsy and thin, it will require supports to print, and you'll need 4 x [4mm M2 countersunk screws](https://amzn.to/2Eaz9wl) to assemble.  I don't recommend this enclosure unless you can't get the standard enclosure to fit in your workbox.
* **[HASwitchPlate_rear_dev.stl](HASwitchPlate_rear_dev.stl)** The `dev` enclosure has USB, SD card, and Nextion XHP connector exposed for development/test purposes.  This is unsafe to install in your workbox.

### Desktop models

An enclosure designed for desktop (table, bedstand, etc) use has been developed.  The enclosure will fit the standard PCB, WeMos D1 Mini, and Nextion 2.4" but will not allow installation or use of the AC PSU.  Power is provided by USB connection to the WeMos D1 Mini.

* **[HASwitchPlate_desktop_front.stl](HASwitchPlate_desktop_front.stl)** Front panel for desktop use with opening for SD card access
* **[HASwitchPlate_desktop_rear.stl](HASwitchPlate_desktop_rear.stl)** Rear enclosure for desktop use with openings for SD card, USB, and Nextion Serial access
* **[HASwitchPlate_desktop_base.stl](HASwitchPlate_desktop_base.stl)** Handy base for desktop use.  Print with higher infill to add mass to weigh it down a bit.

## 3D Printing Notes

### FDM affordance

The careful observer might note that the dimensions of the model vary just slightly from the [published dimensions](https://www.itead.cc/wiki/images/a/ad/2.4%27%27_Nextion_Dimension.pdf) of the panel used in this project.  This has been done to accommodate the nature of FDM 3D printing, which means that other production technologies may require slight modifications to make everything fit snug.  The STLs are published in the correct orientation for printing.

### Filament

I printed these two parts with [AmazonBasics White PETG](https://amzn.to/2I6ctPd) on a [Prusa i3 MK3](https://shop.prusa3d.com/en/3d-printers/180-original-prusa-i3-mk3-kit.html) with 20% infill, .15mm layers, no supports, and 6 bottom layers.  PETG provides good flexibility when mounting the device into your wall, as sometimes the drywall, workbox, etc require a little bit of flex.  PLA might work, but may crack in some installations.  If you have both on hand, print the front in PETG and the back in PLA.

### Inserts

The mounting holes for the Nextion panel are sized to fit [M2 x 3mm threaded inserts](https://amzn.to/2N511Fh) but should accept an M3 screw (tightly).  See [the enclosure build documentation](../Documentation/04_Project_Enclosure.md#threaded-inserts) for more details.

### SketchUp

The SketchUp file included here is dimensioned in meters but 1m == 1mm due to issues with how SketchUp (doesn't) handle small dimensions.  If you intend to modify the provided SketchUp model, export to STL in meters then import for print in mm (the standard setting for most slicers) and you'll be fine.  The included STLs are ready to slice as-is.

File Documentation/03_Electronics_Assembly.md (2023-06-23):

# Electronics Assembly

## Test Assembly

Once the [ESP8266](01_Arduino_Sketch.md) and [Nextion](02_Nextion_HMI.md) firmware images have been flashed, you can connect the two devices together using the following wiring map:

| WeMos Pin | Nextion Cable |
|---|---|
| 5V | Red |
| GND | Black |
| D7 | Blue |
| D4 | Yellow |

### First-time Setup

With your device flashed and wired up, plug the WeMos into a USB port to power up your HASP.  You should be presented with an initialization screen and then information regarding WiFi access along with a QR code for easy connection.  With a PC or mobile device, connect to the WiFi SSID and password displayed on the Nextion (or serial output if you don't have the Nextion ready).  You should be prompted to open a [configuration website](http://192.168.4.1) which will allow you to configure HASP to connect to your WiFi network.  You can set the MQTT broker information and admin credentials now, or use the web interface to do so later.  Once you `save settings` the device will connect to your network.  Congratulations, you are now online!

WiFi Config 0 WiFi Config 1 WiFi Config 2

If you are still testing the HASP before complete assembly, continue to the [Home Assistant section](05_Home_Assistant.md) to configure your Home Assistant installation to support your HASP device.

---

## Complete Electronics Assembly

### BOM

* [Nextion 2.4" LCD Touchscreen display](https://amzn.to/2RksiXr)
* [WeMos D1 Mini ESP8266 WiFi microcontroller](https://amzn.to/2UZlga4)
* [Mean Well IRM-03-5 AC to 5VDC Power supply](https://amzn.to/2UUWGa8)
* [2N3904 NPN Transistor](https://amzn.to/2TRuwwD)
* [1k Ohm Resistor](https://amzn.to/2Ec3kTZ)
* [4pin 2.54mm JST-XH PCB header](https://amzn.to/2Eaywmt) *(note that these are the knockoff 2.54mm versions of the 2.50 XH series from JST.  What they lack for in authenticity they make up for in ubiquity and dirt cheap pricing)*
* [PCB](../PCB)
* [6" each of white and black 300V 18AWG stranded power cables](https://amzn.to/2EcMmoA)

> ## WARNING: do not connect AC power and USB at the same time, as there is a chance you could fry your USB ports.  Always disconnect AC before connecting USB or serial to the ESP8266 and Nextion panel (or doing anything else to the device for that matter)

### PCB Unassembled

This is what your PCB should look like from the top before you've placed any of the components.

PCB Unassembled

### PCB Assembled

Now place the components, taking care to orient the WeMos D1 Mini, Mean Well Power Supply, and JST-XH header as shown in the image below.

PCB Assembled

### Transistor soldering

The transistor and resistor act as a switch on the GND connection for the Nextion LCD.  This allows the HASP to reboot the LCD in the event of a failed LCD firmware update.  The pads on the transistor are a little close together, so take care when soldering here and use as little solder as possible.  **The LCD will not power on until the ESP8266 code is flashed and running**, sending power to the "switch" to turn on the LCD.  If you've flashed the ESP8266 code to the WeMos, you've connected the LCD, you can see the program running in the serial console, and the display isn't powering on... you almost certainly have a problem with the soldering job on the transistor.  If you just can't make it work, that's OK!  Simply cut the resistor out of the circuit (important!), and then you can bridge the 3 pads for the transistor together with a glob of solder.  This will disable the power switch for the LCD, which might mean pulling the device out of the wall if an LCD firmware update fails but will not otherwise impact daily operation.

### High voltage AC cabling

The AC power cables should be at least [18AWG 300V stranded cable](https://amzn.to/2EcMmoA) with a white jacket soldered to the `AC/N` pad on the PCB and a similar wire with a black jacket soldered to `AC/L`.  These are fed through a [rubber push-in grommet](https://amzn.to/2N6Etny) mounted into the rear enclosure.  I've had good luck stripping an existing 3 conductor power cord and using the black/white wires inside.

### Nextion LCD Modification

The Nextion LCD can be modified to give a little extra room around the screw lugs which may help with mounting in some work boxes.  If you have the means to do so, you can use a hot air gun to remove the 4-pin JST XHP connector from the PCB and then use the [`lcdmod` rear enclosure model](../3D_Printable_Models/HASwitchPlate_rear_lcdmod.stl) for some extra room in your box.  If you don't have hot air, some careful use of side cutters or a rotary tool may also do the job.  Be careful not to lift any traces as it's easy to do when applying mechanical force the connector.

In any event, you're going to need to solder the cable harness included with the Nextion display directly to the pins as shown in the image below.  This demonstrates a panel with the connector removed, but you also solder the cable harness directly to the legs of the existing connector with a simple soldering iron with little trouble.  After soldering the cables in place and confirming everything works, I like to put a bit of hot glue over the wires to provide some measure of strain relief.

Nextion_LCD_modification

### DC Power Option

The [Mean Well IRM-03-5 AC to 5VDC Power supply](https://amzn.to/2UUWGa8) can be substituted with any of the following [Mean Well SLC03-series DC-DC power supplies](http://www.meanwellusa.com/productPdf.aspx?i=786) if you'd prefer a low-voltage DC option.  This should be suitable for use over existing Cat5 cables, speaker cables, alarm cabling, etc already in your wall.  Check to confirm that the existing cable wire gauge will be safe for the load you will be putting on the system, and try not to put voltage down a wire where other expensive and flammable things might be connected which aren't expecting it.

| Model | Input Voltage Range |
|---|---|
| SLC03A-05 | 9-18VDC |
| SLC03B-05 | 18-36VDC |
| SLC03C-05 | 36-75VDC |

These DC-DC supplies are smaller than the AC-DC supply and have a different footprint on the board.  Position the supply as shown below.

PCB_DC_Assembled

### Schematic for protoboard assembly

This project was initially built on a [4x6 protoboard](https://amzn.to/2N6IqbM) and the enclosure should still accommodate this approach if you have boards on hand.  Note that this approach is probably dangerous as 120VAC and protoboards are a bad mix.

The parts should be fit much as shown in the PCB images above.  In my case the bottom-most row of 8 pins on the WeMos D1 mini [as shown in this image](https://raw.githubusercontent.com/aderusha/HASwitchPlate/master/Documentation/Images/Perfboard_Assembly_Parts_Installed.jpg) would not fit on the perforated area of the board, instead I soldered the pin header with the pins projecting upward from the board to attach wires above.  It wasn't pretty, it's likely not safe, and you really should use the PCB.

Schematic
